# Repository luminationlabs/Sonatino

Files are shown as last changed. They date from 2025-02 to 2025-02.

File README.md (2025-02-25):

# Sonatino PCB Design Files

Sonatino is a powerful ESP32-S3-based audio development board that combines high-quality audio processing capabilities with wireless connectivity and extensive I/O options.

## Features

- ESP32-S3-WROOM-1U MCU with 16MB flash and 8MB PSRAM
- High-quality 24-bit/192kHz DAC (WM8524, stereo) and ADC (WM8782, mono)
- 3.2W speaker amplifier (MAX98357A)
- TRRS audio jack supporting input and output
- Stereo headphone amplifier and microphone preamp
- microSD card slot
- WiFi and Bluetooth 5.0 LE connectivity
- USB-C for programming and power
- Battery support with charging circuit
- Configurable audio I/O levels
- Compact form factor

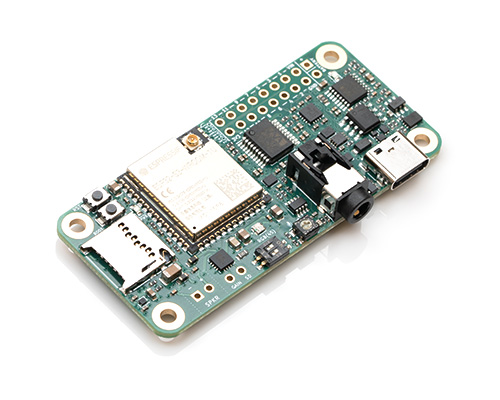
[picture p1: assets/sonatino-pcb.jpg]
Sonatino PCB


## Component Availability

The ADC that Sonatino uses (Cirrus Logic WM8782) has been discontinued by its manufacturer. Some suppliers may still have limited stock, but ultimately it needs to be replaced with a similar ADC (possibly a Texas Instruments PCM186x chip or an audio CODEC to replace the ADC and DAC). In either case, the PCB schematic and layout will need to be modified as there is no drop-in replacement.

## Board Variants

### [Sonatino](https://github.com/luminationlabs/Sonatino) (`main` branch)

- Standard board documented at [sonatino.com](https://sonatino.com)
- Based on ESP32-S3-WROOM-1U
- Uses Bluetooth 5.0 LE **without** support for Bluetooth audio

### [Sonatino - Bluetooth Audio Edition](https://github.com/luminationlabs/Sonatino/tree/btaudio) (`btaudio` branch)

- Unreleased board
- Based on ESP32-WROOM-32UE
- Uses Bluetooth v4.2 BR/EDR and BLE **with** support for Bluetooth audio (A2DP)
- Has fewer exposed GPIO pins (10 vs 13)
- Requires configuration using shift register on GPIO 17, 18, and 19

## License and Trademark Notice

OSHW Logo
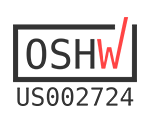
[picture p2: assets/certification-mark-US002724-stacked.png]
Certification Mark


Certified open source hardware ([oshwa.org/cert](https://oshwa.org/cert)) - [OSHW] US002724

The design files for this PCB are open-source hardware under [CERN OHL-P v2.0](https://ohwr.org/cern_ohl_p_v2.txt).

The name "Sonatino" and the associated logo are trademarks of Lumination Labs, Inc. Other manufacturers may use the hardware design but may not use the "Sonatino" branding without permission.

The documentation for Sonatino is copyrighted by Lumination Labs, Inc. and provided for informational purposes only. Redistribution or modification of the documentation requires written permission.

## Documentation

For detailed documentation, examples, and a getting started guide, visit:

- [Documentation](https://sonatino.com/docs/)
- [Example Projects](https://github.com/luminationlabs/Sonatino-Examples)

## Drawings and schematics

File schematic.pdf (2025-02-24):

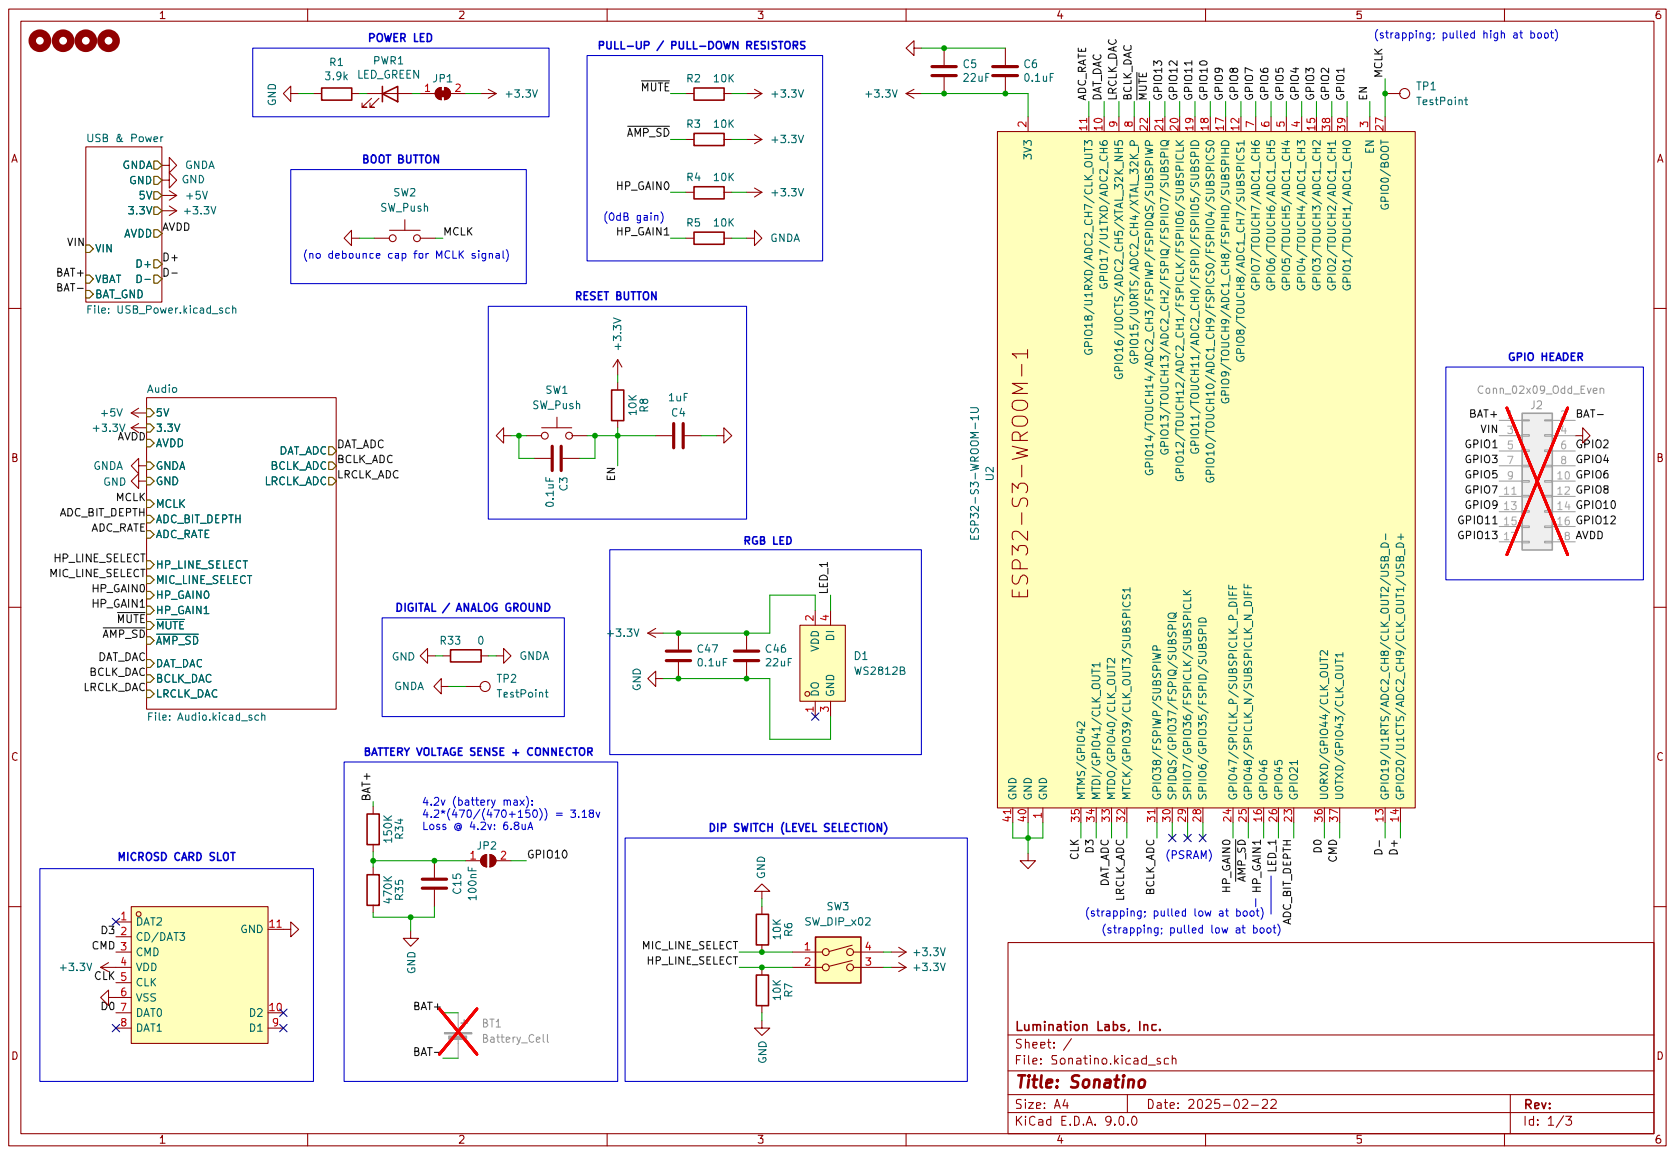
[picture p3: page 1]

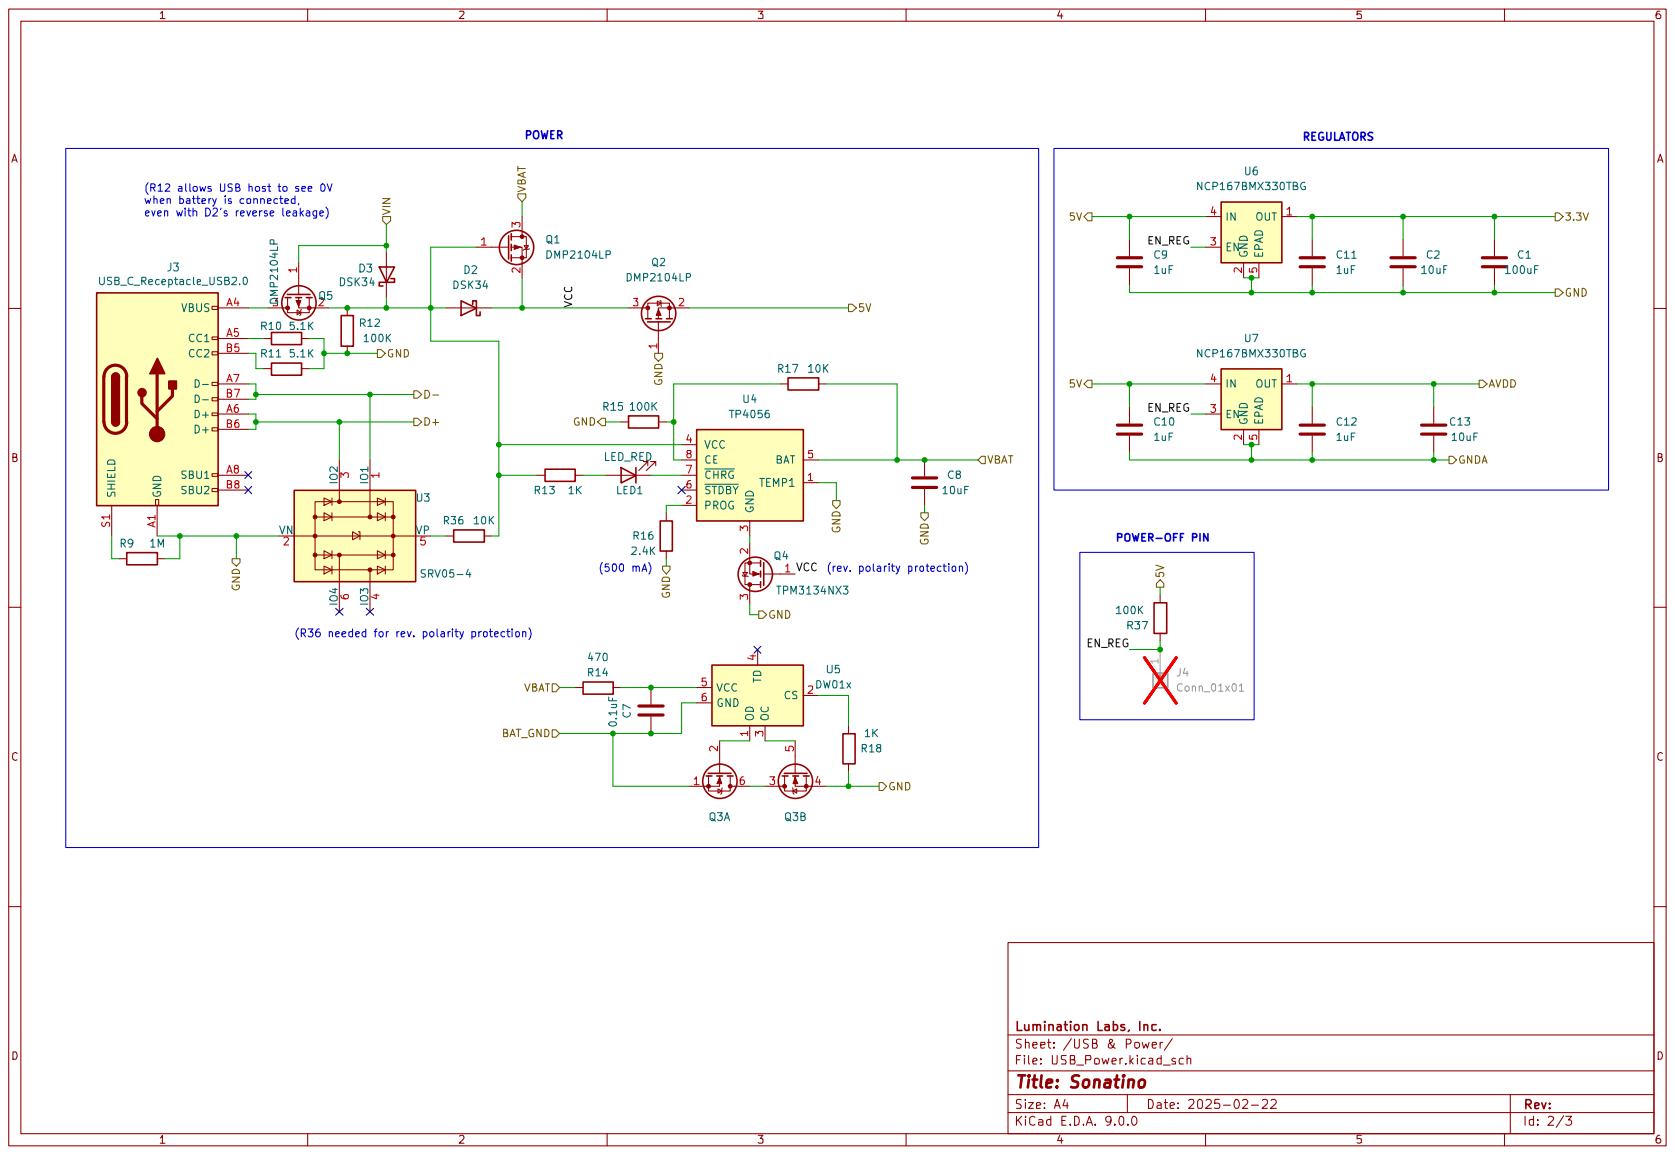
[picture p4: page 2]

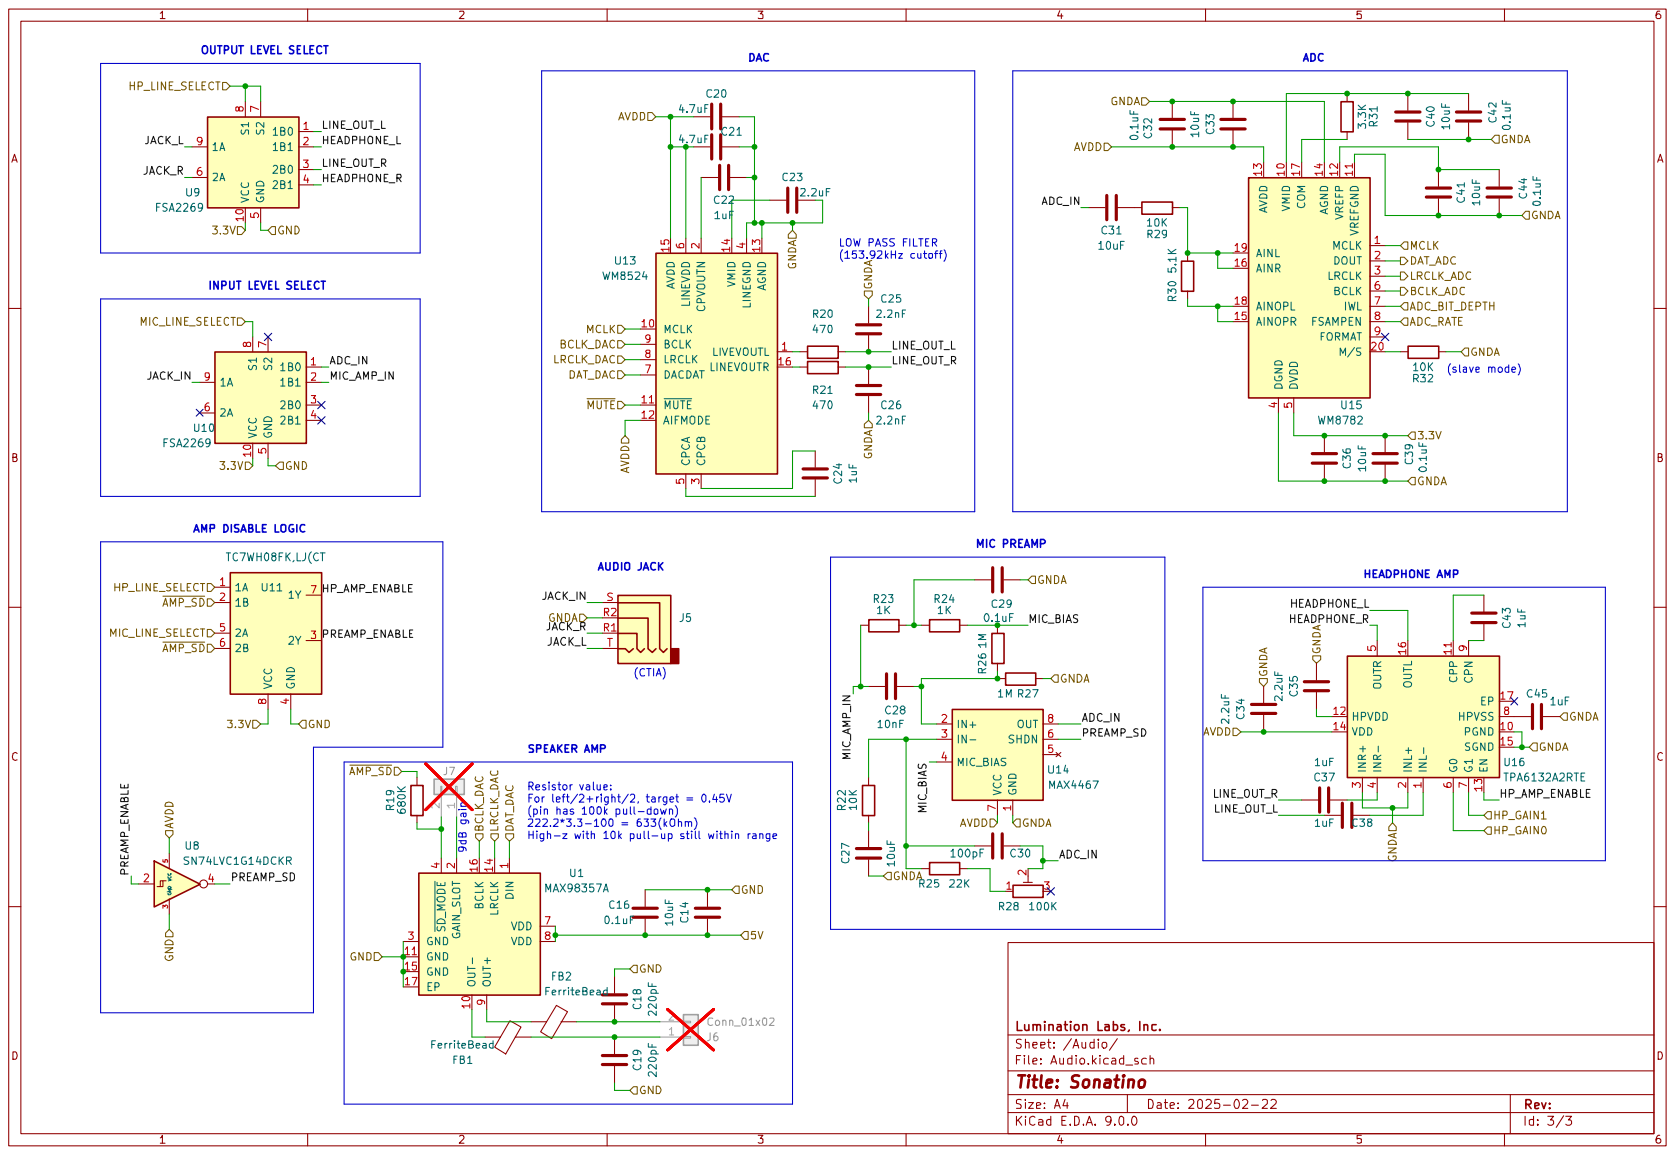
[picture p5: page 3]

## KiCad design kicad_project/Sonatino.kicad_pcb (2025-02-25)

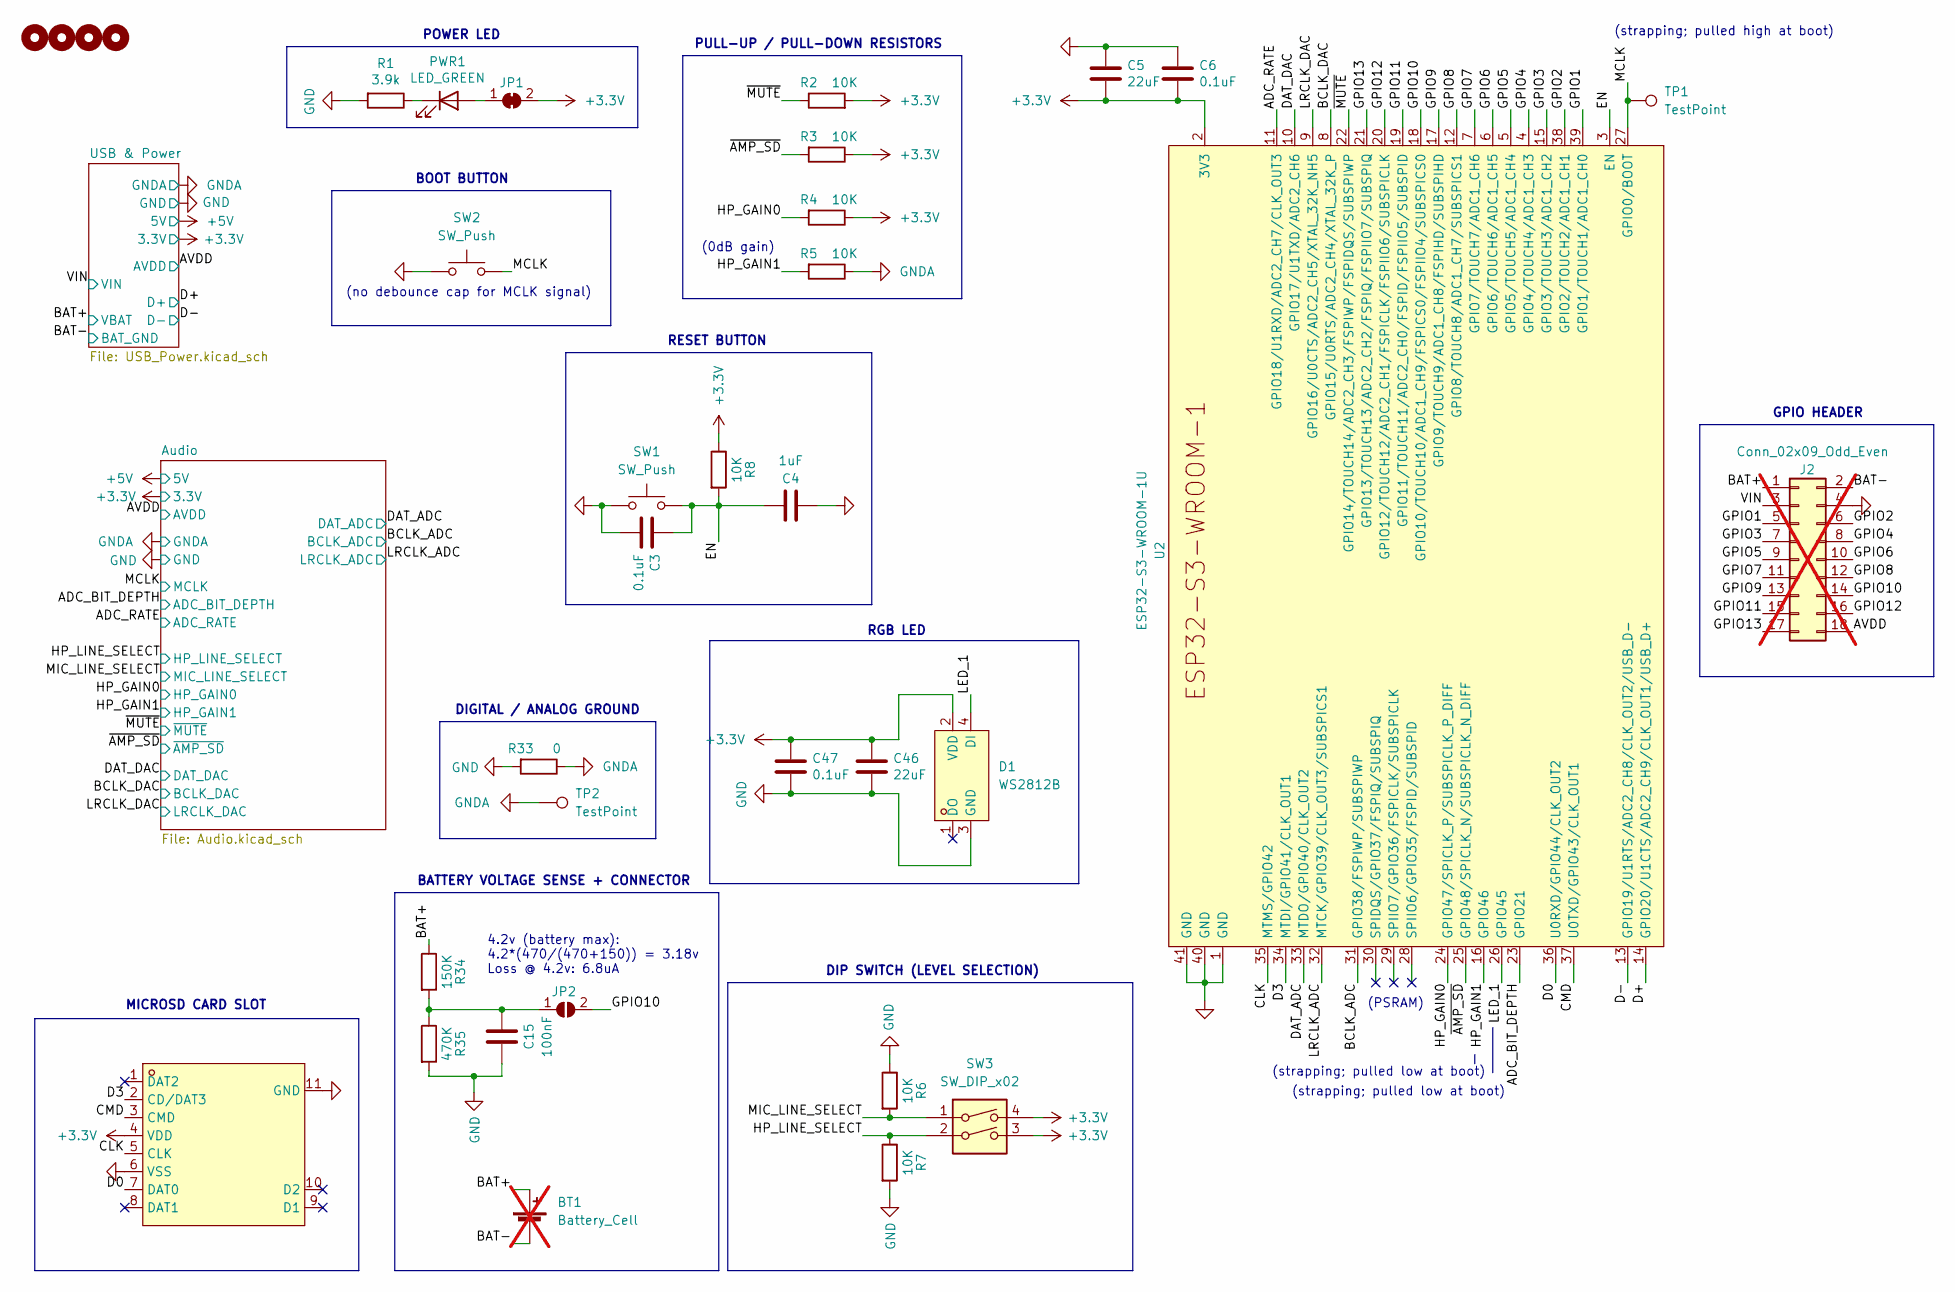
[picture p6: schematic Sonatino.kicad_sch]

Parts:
BT1: Battery_Cell; JST_PH_S2B-PH-SM4-TB_1x02-1MP_P2.00mm_Horizontal; LCSC 0; not fitted
C3, C6, C47: 0.1uF; C_0402_1005Metric; LCSC C307331
C4: 1uF; C_0402_1005Metric; LCSC C52923
C5, C46: 22uF; C_0805_2012Metric; LCSC C45783
C15: 100nF; C_0402_1005Metric; LCSC C1525
Card2: TF-008; TF-SMD_TF-008; LCSC C428465
D1: WS2812B; LED-SMD_4P-L1.6-W1.5_XL-1615RGBC-WS2812B; LCSC C5349954
H1, H3, H5, H7: MountingHole; MountingHole_2.7mm_Pad; LCSC 0
J2: Conn_02x09_Odd_Even; PinHeader_2x09_P2.54mm_Vertical; LCSC 0; not fitted
JP1: SolderJumper_2_Bridged; SolderJumper-2_P1.3mm_Bridged_Pad1.0x1.5mm; LCSC 0
JP2: SolderJumper_2_Open; SolderJumper-2_P1.3mm_Open_TrianglePad1.0x1.5mm; LCSC 0
PWR1: LED_GREEN; LED_0603_1608Metric; LCSC C12624
R1: 3.9k; R_0402_1005Metric; LCSC C51721
R2, R3, R4, R5, R6, R7, R8: 10K; R_0402_1005Metric; LCSC C25744
R33: 0; R_0603_1608Metric; LCSC C21189
R34: 150K; R_0402_1005Metric; LCSC C102813
R35: 470K; R_0402_1005Metric; LCSC C25790
SW1, SW2: SW_Push; SW_Push_1P1T_NO_3.95_2.9; LCSC C354946
SW3: SW_DIP_x02; SW_DIP_SPSTx02_Slide_Omron_A6H-2101_W6.15mm_P1.27mm; LCSC C224995
TP1, TP2: TestPoint; TestPoint_Pad_D1.5mm; LCSC 0
U2: ESP32-S3-WROOM-1U; LCSC C3013946

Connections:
+3.3V: C5.2, C6.2, C46.1, C47.1, Card2.4 (VDD), D1.2 (VDD), JP1.2 (B), R2.2, R3.1, R4.1, R8.1, SW3.3, SW3.4, U2.2 (3V3); also elsewhere on the board
/ADC_BIT_DEPTH: U2.23 (GPIO21); also elsewhere on the board
/ADC_RATE: U2.11 (GPIO18/U1RXD/ADC2_CH7/CLK_OUT3); also elsewhere on the board
/AVDD: J2.18; also elsewhere on the board
/BAT+: BT1.1 (+), J2.1, R34.1; also elsewhere on the board
/BAT-: BT1.2 (-), J2.2; also elsewhere on the board
/BCLK_ADC: U2.31 (GPIO38/FSPIWP/SUBSPIWP); also elsewhere on the board
/BCLK_DAC: U2.8 (GPIO15/U0RTS/ADC2_CH4/XTAL_32K_P); also elsewhere on the board
/CLK: Card2.5 (CLK), U2.35 (MTMS/GPIO42)
/CMD: Card2.3 (CMD), U2.37 (U0TXD/GPIO43/CLK_OUT1)
/D0: Card2.7 (DAT0), U2.36 (U0RXD/GPIO44/CLK_OUT2)
/D3: Card2.2 (CD/DAT3), U2.34 (MTDI/GPIO41/CLK_OUT1)
/D+: U2.14 (GPIO20/U1CTS/ADC2_CH9/CLK_OUT1/USB_D+); also elsewhere on the board
/D-: U2.13 (GPIO19/U1RTS/ADC2_CH8/CLK_OUT2/USB_D-); also elsewhere on the board
/DAT_ADC: U2.33 (MTDO/GPIO40/CLK_OUT2); also elsewhere on the board
/DAT_DAC: U2.10 (GPIO17/U1TXD/ADC2_CH6); also elsewhere on the board
/EN: C3.1, C4.2, R8.2, SW1.2, U2.3 (EN)
/GPIO1: J2.5, U2.39 (GPIO1/TOUCH1/ADC1_CH0)
/GPIO2: J2.6, U2.38 (GPIO2/TOUCH2/ADC1_CH1)
/GPIO3: J2.7, U2.15 (GPIO3/TOUCH3/ADC1_CH2)
/GPIO4: J2.8, U2.4 (GPIO4/TOUCH4/ADC1_CH3)
/GPIO5: J2.9, U2.5 (GPIO5/TOUCH5/ADC1_CH4)
/GPIO6: J2.10, U2.6 (GPIO6/TOUCH6/ADC1_CH5)
/GPIO7: J2.11, U2.7 (GPIO7/TOUCH7/ADC1_CH6)
/GPIO8: J2.12, U2.12 (GPIO8/TOUCH8/ADC1_CH7/SUBSPICS1)
/GPIO9: J2.13, U2.17 (GPIO9/TOUCH9/ADC1_CH8/FSPIHD/SUBSPIHD)
/GPIO10: J2.14, JP2.2 (B), U2.18 (GPIO10/TOUCH10/ADC1_CH9/FSPICS0/FSPIIO4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)
/GPIO11: J2.15, U2.19 (GPIO11/TOUCH11/ADC2_CH0/FSPID/FSPIIO5/S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)
/GPIO12: J2.16, U2.20 (GPIO12/TOUCH12/ADC2_CH1/FSPICLK/FSPIIO6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)
/GPIO13: J2.17, U2.21 (GPIO13/TOUCH13/ADC2_CH2/FSPIQ/FSPIIO7/S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)
/HP_GAIN0: R4.2, U2.24 (GPIO47/SPICLK_P/SUBSPICLK_P_DIFF); also elsewhere on the board
/HP_GAIN1: R5.2, U2.16 (GPIO46); also elsewhere on the board
/HP_LINE_SELECT: R7.1, SW3.2; also elsewhere on the board
/LED_1: D1.4 (DI), U2.26 (GPIO45)
/LRCLK_ADC: U2.32 (MTCK/GPIO39/CLK_OUT3/SUBSPICS1); also elsewhere on the board
/LRCLK_DAC: U2.9 (GPIO16/U0CTS/ADC2_CH5/XTAL_32K_NH5); also elsewhere on the board
/MCLK: SW2.2, TP1.1, U2.27 (GPIO0/BOOT); also elsewhere on the board
/MIC_LINE_SELECT: R6.2, SW3.1; also elsewhere on the board
/VIN: J2.3; also elsewhere on the board
/~AMP_SD: R3.2, U2.25 (GPIO48/SPICLK_N/SUBSPICLK_N_DIFF); also elsewhere on the board
/~MUTE: R2.1, U2.22 (GPIO14/TOUCH14/ADC2_CH3/FSPIWP/FSPIDQS/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); also elsewhere on the board
GND: C3.2, C4.1, C5.1, C6.1, C15.1, C46.2, C47.2, Card2.6 (VSS), Card2.11 (GND), D1.3 (GND), J2.4, R1.2, R6.1, R7.2, R33.2, R35.2, SW1.1, SW2.1, U2.1 (GND), U2.40 (GND), U2.41 (GND); also elsewhere on the board
GNDA: R5.1, R33.1, TP2.1; also elsewhere on the board
unnamed: JP1.1 (A), PWR1.2 (A)
unnamed: C15.2, JP2.1 (A), R34.2, R35.1
unnamed: PWR1.1 (K), R1.1

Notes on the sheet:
(PSRAM)
(no debounce cap for MCLK signal)
DIP SWITCH (LEVEL SELECTION)
(strapping; pulled low at boot)
(0dB gain)
BOOT BUTTON
GPIO HEADER
(strapping; pulled high at boot)
RESET BUTTON
4.2v (battery max): 4.2*(470/(470+150)) = 3.18v Loss @ 4.2v: 6.8uA
DIGITAL / ANALOG GROUND
BATTERY VOLTAGE SENSE + CONNECTOR
RGB LED
MICROSD CARD SLOT
PULL-UP / PULL-DOWN RESISTORS
POWER LED

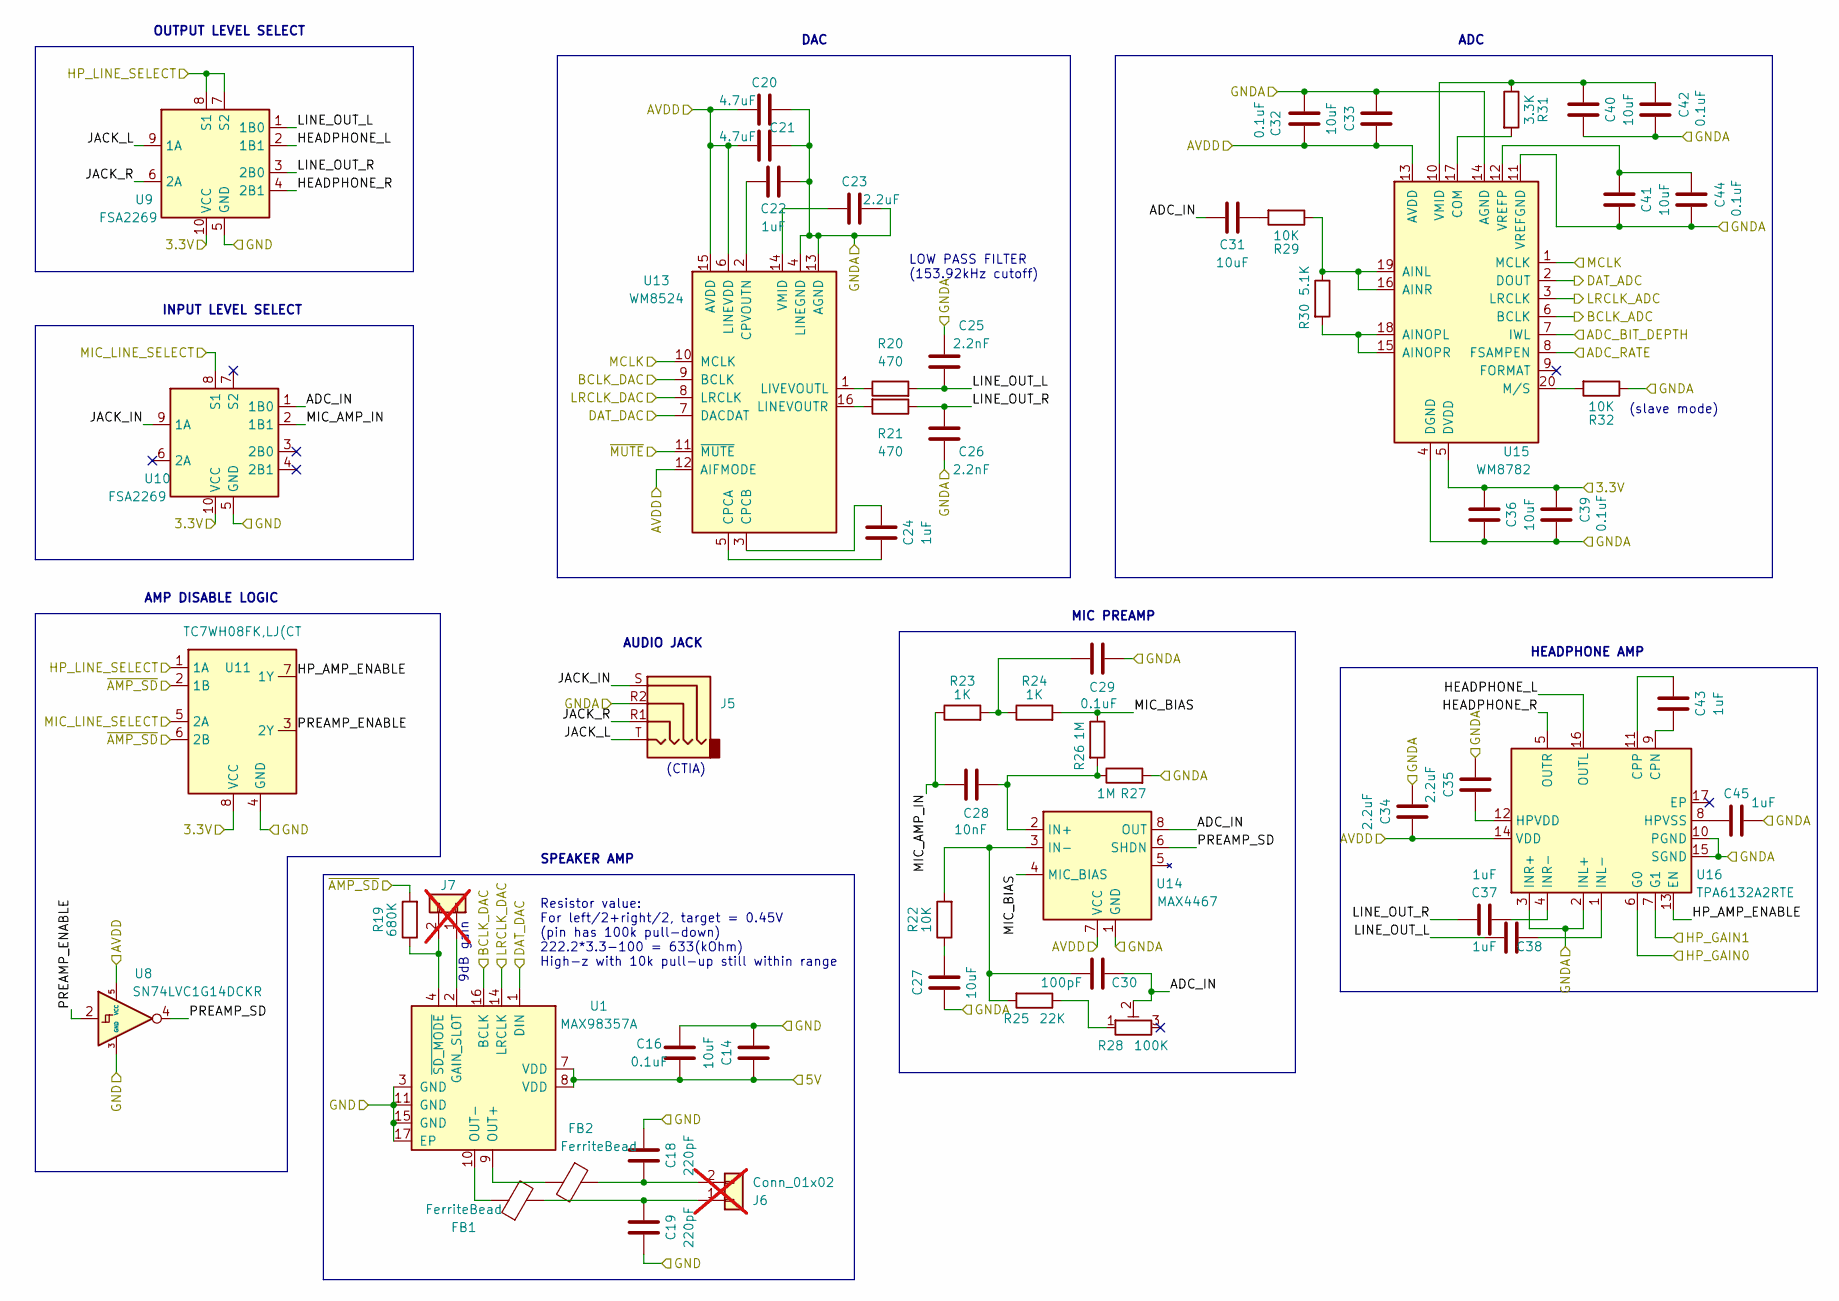
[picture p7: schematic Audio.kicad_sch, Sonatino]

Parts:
C14: 10uF; C_0805_2012Metric; LCSC C15850
C16: 0.1uF; C_0805_2012Metric; LCSC C49678
C18, C19: 220pF; C_0402_1005Metric; LCSC C1530
C20, C21: 4.7uF; C_0402_1005Metric; LCSC C23733
C22, C37, C38, C43, C45: 1uF; C_0402_1005Metric; LCSC C52923
C23, C34, C35: 2.2uF; C_0402_1005Metric; LCSC C12530
C24: 1uF; C_0603_1608Metric; LCSC C15849
C25, C26: 2.2nF; C_0402_1005Metric; LCSC C1531
C27, C31, C33, C36, C40, C41: 10uF; C_0402_1005Metric; LCSC C15525
C28: 10nF; C_0402_1005Metric; LCSC C15195
C29, C32, C39, C42, C44: 0.1uF; C_0402_1005Metric; LCSC C307331
C30: 100pF; C_0402_1005Metric; LCSC C1546
FB1, FB2: FerriteBead; L_0603_1608Metric; LCSC C1002
J5: AudioJack4; PJ-321B; LCSC C692436
J6: Conn_01x02; PinHeader_1x02_P2.54mm_Vertical; LCSC 0; not fitted
J7: Conn_01x02; PinHeader_1x02_P2.54mm_Vertical; not fitted
R19: 680K; R_0603_1608Metric; LCSC C25822
R20, R21: 470; R_0402_1005Metric; LCSC C25117
R22, R29, R32: 10K; R_0402_1005Metric; LCSC C25744
R23, R24: 1K; R_0402_1005Metric; LCSC C11702
R25: 22K; R_0402_1005Metric; LCSC C25768
R26, R27: 1M; R_0402_1005Metric; LCSC C26083
R28: 100K; G32AT-B103; LCSC C128123
R30: 5.1K; R_0402_1005Metric; LCSC C25905
R31: 3.3K; R_0402_1005Metric; LCSC C25890
U1: MAX98357A; TQFN-16-1EP_3x3mm_P0.5mm_EP1.23x1.23mm; JLCPCB Rotation Offset 270
U8: SN74LVC1G14DCKR; SOT-353_SC-70-5; LCSC C2976657
U9, U10: FSA2269; Fairchild_MicroPak-10_2.10x1.6mm_P0.5mm; LCSC C895405
U11: TC7WH08FK,LJ(CT; VSSOP-8_2.3x2mm_P0.5mm; LCSC C2880449
U13: WM8524; TSSOP-16_4.4x5mm_P0.65mm; LCSC C146242
U14: MAX4467; SOT-23-8; LCSC C490742
U15: WM8782; SSOP-20_5.3x7.2mm_P0.65mm; LCSC C323842
U16: TPA6132A2RTE; WQFN-16-1EP_3x3mm_P0.5mm_EP1.6x1.6mm_ThermalVias; LCSC C69901

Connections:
+3.3V: C36.2, C39.1, U9.10 (VCC), U10.10 (VCC), U11.8 (VCC), U15.5 (DVDD); also elsewhere on the board
+5V: C14.2, C16.1, U1.7 (VDD), U1.8 (VDD); also elsewhere on the board
/ADC_BIT_DEPTH: U15.7 (IWL); also elsewhere on the board
/ADC_RATE: U15.8 (FSAMPEN); also elsewhere on the board
/AVDD: C20.1, C21.1, C32.1, C33.2, C34.2, U8.5 (VCC), U13.6 (LINEVDD), U13.12 (AIFMODE), U13.15 (AVDD), U14.7 (VCC), U15.13 (AVDD), U16.14 (VDD); also elsewhere on the board
/Audio/ADC_IN: C30.2, C31.1, R28.2, U10.1 (1B0), U14.8 (OUT)
/Audio/HEADPHONE_L: U9.2 (1B1), U16.16 (OUTL)
/Audio/HEADPHONE_R: U9.4 (2B1), U16.5 (OUTR)
/Audio/HP_AMP_ENABLE: U11.7 (1Y), U16.13 (EN)
/Audio/JACK_IN: J5.S, U10.9 (1A)
/Audio/JACK_L: J5.T, U9.9 (1A)
/Audio/JACK_R: J5.R1, U9.6 (2A)
/Audio/LINE_OUT_L: C25.1, C38.1, R20.2, U9.1 (1B0)
/Audio/LINE_OUT_R: C26.2, C37.2, R21.1, U9.3 (2B0)
/Audio/MIC_AMP_IN: C28.2, R23.1, U10.2 (1B1)
/Audio/MIC_BIAS: R24.2, R26.1, U14.4 (MIC_BIAS)
/Audio/PREAMP_ENABLE: U8.2, U11.3 (2Y)
/Audio/PREAMP_SD: U8.4, U14.6 (SHDN)
/BCLK_ADC: U15.6 (BCLK); also elsewhere on the board
/BCLK_DAC: U1.16 (BCLK), U13.9 (BCLK); also elsewhere on the board
/DAT_ADC: U15.2 (DOUT); also elsewhere on the board
/DAT_DAC: U1.1 (DIN), U13.7 (DACDAT); also elsewhere on the board
/HP_GAIN0: U16.6 (G0); also elsewhere on the board
/HP_GAIN1: U16.7 (G1); also elsewhere on the board
/HP_LINE_SELECT: U9.7 (S2), U9.8 (S1), U11.1 (1A); also elsewhere on the board
/LRCLK_ADC: U15.3 (LRCLK); also elsewhere on the board
/LRCLK_DAC: U1.14 (LRCLK), U13.8 (LRCLK); also elsewhere on the board
/MCLK: U13.10 (MCLK), U15.1 (MCLK); also elsewhere on the board
/MIC_LINE_SELECT: U10.8 (S1), U11.5 (2A); also elsewhere on the board
/~AMP_SD: R19.2, U11.2 (1B), U11.6 (2B); also elsewhere on the board
/~MUTE: U13.11 (~MUTE); also elsewhere on the board
GND: C14.1, C16.2, C18.2, C19.1, U1.3 (GND), U1.11 (GND), U1.15 (GND), U1.17 (EP), U8.3 (GND), U9.5 (GND), U10.5 (GND), U11.4 (GND); also elsewhere on the board
GNDA: C20.2, C21.2, C22.2, C23.1, C25.2, C26.1, C27.2, C29.1, C32.2, C33.1, C34.1, C35.1, C36.1, C39.2, C40.1, C41.1, C42.2, C44.2, C45.1, J5.R2, R27.2, R32.1, U13.4 (LINEGND), U13.13 (AGND), U14.1 (GND), U15.4 (DGND), U15.11 (VREFGND), U15.14 (AGND), U16.2 (INL+), U16.3 (INR+), U16.10 (PGND), U16.15 (SGND); also elsewhere on the board
unnamed: C27.1, R22.1
unnamed: C29.2, R23.2, R24.1
unnamed: C31.2, R29.2
unnamed: C19.2, FB1.2, J6.1
unnamed: C18.1, FB2.1, J6.2
unnamed: J7.1, U1.2 (GAIN_SLOT)
unnamed: J7.2, R19.1, U1.4 (~SD_MODE)
unnamed: R25.1, R28.1
unnamed: FB2.2, U1.9 (OUT+)
unnamed: FB1.1, U1.10 (OUT-)
unnamed: C24.1, U13.5 (CPCA)
unnamed: C24.2, U13.3 (CPCB)
unnamed: C22.1, U13.2 (CPVOUTN)
unnamed: R21.2, U13.16 (LINEVOUTR)
unnamed: R20.1, U13.1 (LIVEVOUTL)
unnamed: C23.2, U13.14 (VMID)
unnamed: C28.1, R26.2, R27.1, U14.2 (IN+)
unnamed: C30.1, R22.2, R25.2, U14.3 (IN-)
unnamed: R29.1, R30.1, U15.16 (AINR), U15.19 (AINL)
unnamed: R30.2, U15.15 (AINOPR), U15.18 (AINOPL)
unnamed: R31.2, U15.17 (COM)
unnamed: R32.2, U15.20 (M/S)
unnamed: C40.2, C42.1, R31.1, U15.10 (VMID)
unnamed: C41.2, C44.1, U15.12 (VREFP)
unnamed: C43.1, U16.9 (CPN)
unnamed: C43.2, U16.11 (CPP)
unnamed: C35.2, U16.12 (HPVDD)
unnamed: C45.2, U16.8 (HPVSS)
unnamed: C38.2, U16.1 (INL-)
unnamed: C37.1, U16.4 (INR-)

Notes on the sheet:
9dB gain
ADC
MIC PREAMP
LOW PASS FILTER (153.92kHz cutoff)
INPUT LEVEL SELECT
(slave mode)
SPEAKER AMP
AMP DISABLE LOGIC
OUTPUT LEVEL SELECT
AUDIO JACK
Resistor value: For left/2+right/2, target = 0.45V (pin has 100k pull-down) 222.2*3.3-100 = 633(kOhm) High-z with 10k pull-up still within range
DAC
HEADPHONE AMP
(CTIA)

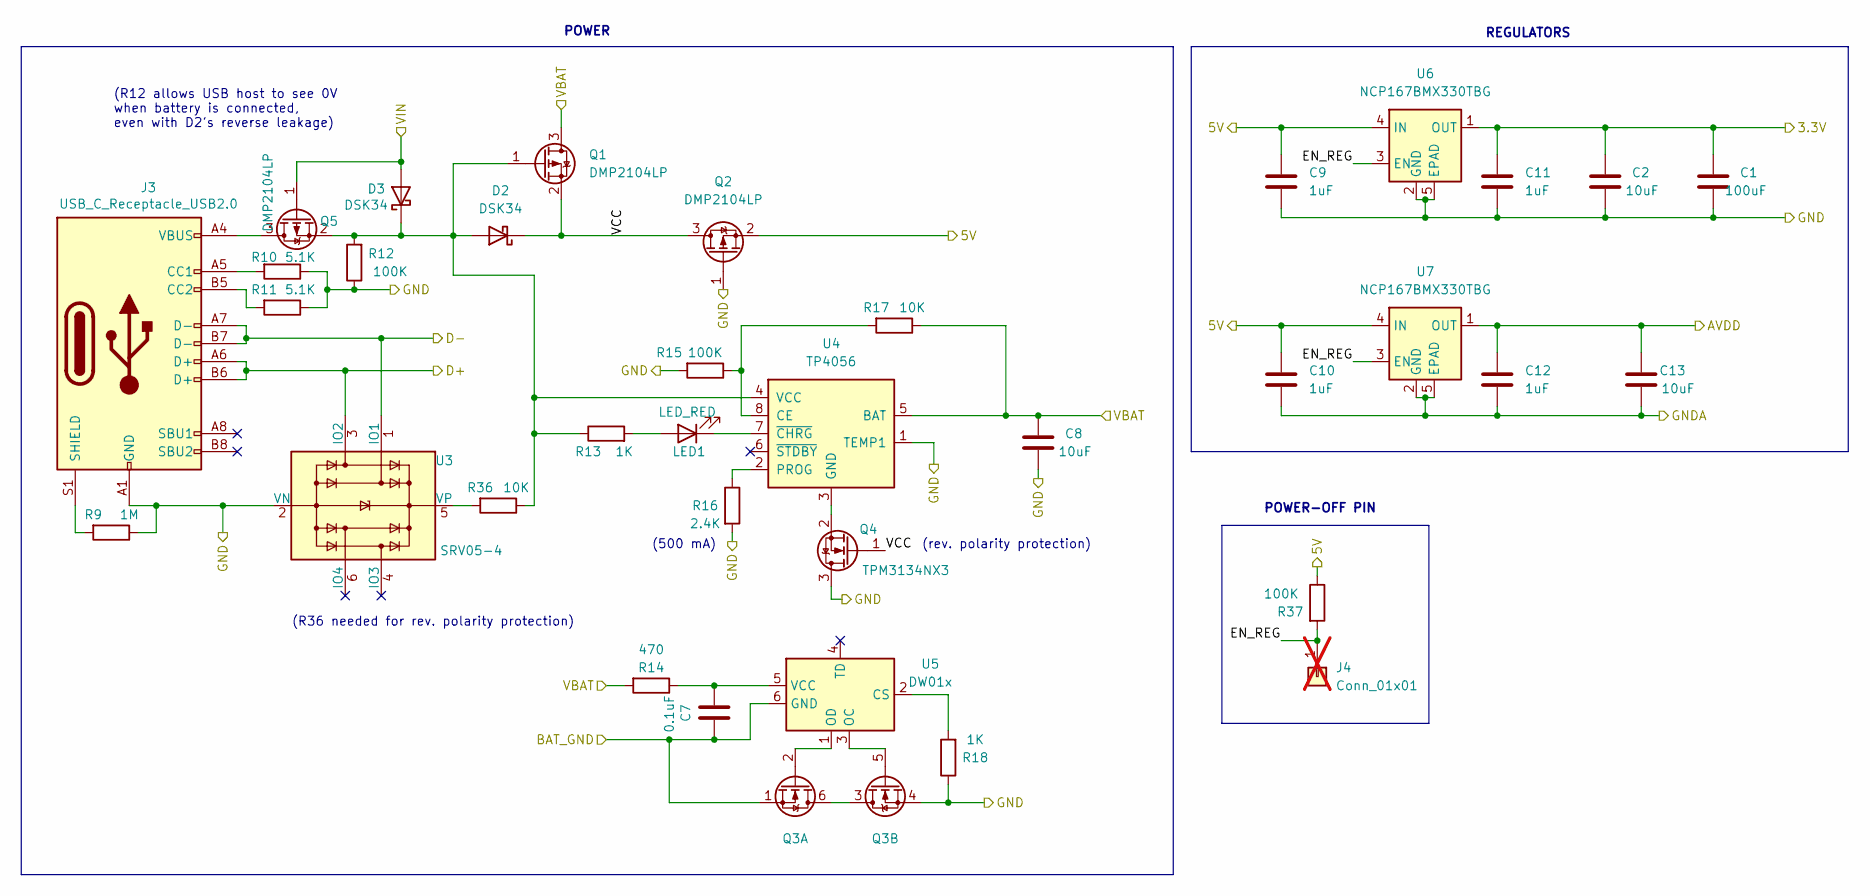
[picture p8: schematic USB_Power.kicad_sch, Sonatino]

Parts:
C1: 100uF; C_1206_3216Metric; LCSC C15008
C2, C13: 10uF; C_0603_1608Metric; LCSC C19702
C7: 0.1uF; C_0402_1005Metric; LCSC C307331
C8: 10uF; C_0402_1005Metric; LCSC C15525
C9, C10, C11, C12: 1uF; C_0402_1005Metric; LCSC C52923
D2, D3: DSK34; SOD-123FL; LCSC C41029
J3: USB_C_Receptacle_USB2.0; USB_C_Receptacle_HRO_TYPE-C-31-M-12; LCSC C165948
J4: Conn_01x01; PinHeader_1x01_P2.54mm_Vertical; LCSC 0; not fitted
LED1: LED_RED; LED_0603_1608Metric; LCSC C2286
Q1, Q2, Q5: DMP2104LP; Diodes_DFN1411-3; LCSC C260933
Q3: HSCC8233; DFN-6-1EP_3x2mm_P0.5mm_EP1.65x1.35mm_Dual_MOSFETs; LCSC C700968
Q4: TPM3134NX3; SOT-723; LCSC C558450
R9: 1M; R_0402_1005Metric; LCSC C26083
R10, R11: 5.1K; R_0402_1005Metric; LCSC C25905
R12, R15, R37: 100K; R_0402_1005Metric; LCSC C25741
R13, R18: 1K; R_0402_1005Metric; LCSC C11702
R14: 470; R_0402_1005Metric; LCSC C25117
R16: 2.4K; R_0402_1005Metric; LCSC C25882
R17, R36: 10K; R_0402_1005Metric; LCSC C25744
U3: SRV05-4; SOT-23-6; LCSC C85364
U4: TP4056; TI_SO-PowerPAD-8; LCSC C16581
U5: DW01x; SOT-23-6; LCSC C351410
U6, U7: NCP167BMX330TBG; OnSemi_XDFN4-1EP_1.0x1.0mm_EP0.52x0.52mm-FIXED; LCSC C892227

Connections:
+3.3V: C1.2, C2.2, C11.1, U6.1 (OUT); also elsewhere on the board
+5V: C9.1, C10.1, Q2.2 (S), R37.1, U6.4 (IN), U7.4 (IN); also elsewhere on the board
/AVDD: C12.1, C13.2, U7.1 (OUT); also elsewhere on the board
/BAT+: C8.2, Q1.3 (D), R14.2, R17.1, U4.5 (BAT); also elsewhere on the board
/BAT-: C7.1, Q3.1 (S), U5.6 (GND); also elsewhere on the board
/D+: J3.A6 (D+), J3.B6 (D+), U3.3 (IO2); also elsewhere on the board
/D-: J3.A7 (D-), J3.B7 (D-), U3.1 (IO1); also elsewhere on the board
/USB & Power/EN_REG: J4.1, R37.2, U6.3 (EN), U7.3 (EN)
/USB & Power/VCC: D2.1 (K), Q1.2 (S), Q2.3 (D), Q4.1 (G)
/VIN: D3.2 (A), Q5.1 (G); also elsewhere on the board
GND: C1.1, C2.1, C8.1, C9.2, C11.2, J3.A1 (GND), J3.A12 (GND), J3.B1 (GND), J3.B12 (GND), Q2.1 (G), Q3.4 (S), Q4.3 (D), R9.1, R10.1, R11.1, R12.1, R15.2, R16.2, R18.1, U3.2 (VN), U4.1 (TEMP1), U6.2 (GND), U6.5 (EPAD); also elsewhere on the board
GNDA: C10.2, C12.2, C13.1, U7.2 (GND), U7.5 (EPAD); also elsewhere on the board
unnamed: D2.2 (A), D3.1 (K), Q1.1 (G), Q5.2 (S), R12.2, R13.1, R36.1, U4.4 (VCC)
unnamed: J3.A5 (CC1), R10.2
unnamed: J3.B5 (CC2), R11.2
unnamed: J3.S1 (SHIELD), R9.2
unnamed: LED1.2 (A), R13.2
unnamed: LED1.1 (K), U4.7 (~CHRG)
unnamed: Q3.3 (D), Q3.6 (D)
unnamed: Q3.2 (G), U5.1 (OD)
unnamed: Q3.5 (G), U5.3 (OC)
unnamed: Q4.2 (S), U4.3 (GND)
unnamed: J3.A4 (VBUS), J3.A9 (VBUS), J3.B4 (VBUS), J3.B9 (VBUS), Q5.3 (D)
unnamed: R36.2, U3.5 (VP)
unnamed: R15.1, R17.2, U4.8 (CE)
unnamed: R16.1, U4.2 (PROG)
unnamed: R18.2, U5.2 (CS)
unnamed: C7.2, R14.1, U5.5 (VCC)

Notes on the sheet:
POWER
(R12 allows USB host to see 0V when battery is connected, even with D2's reverse leakage)
(500 mA)
(R36 needed for rev. polarity protection)
(rev. polarity protection)
POWER-OFF PIN
REGULATORS

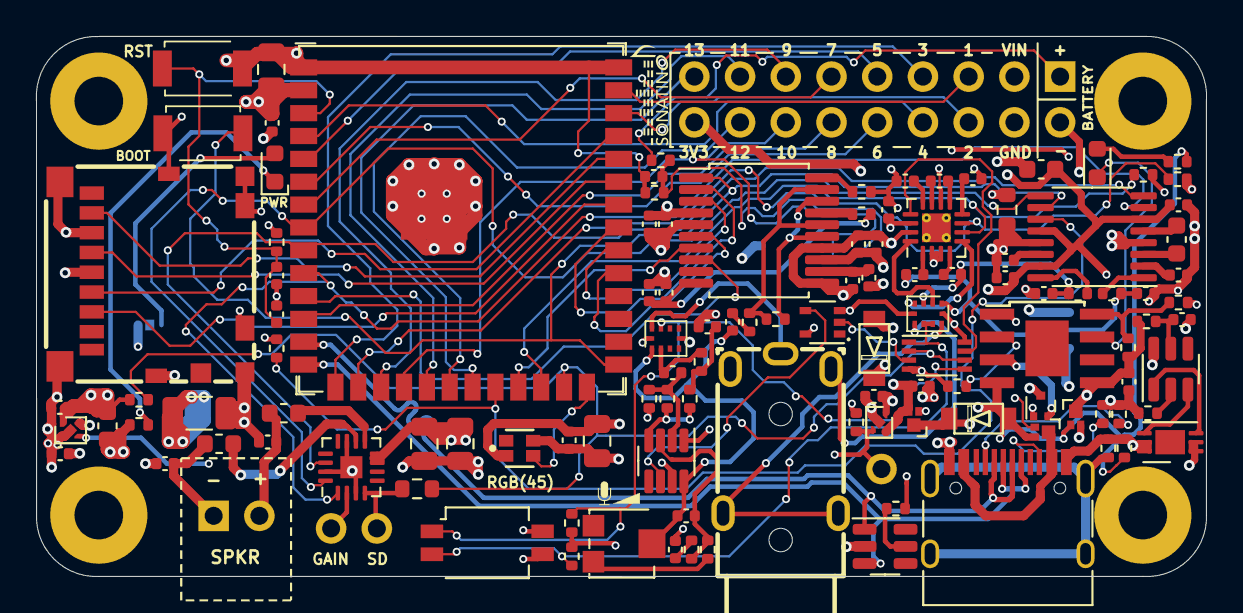
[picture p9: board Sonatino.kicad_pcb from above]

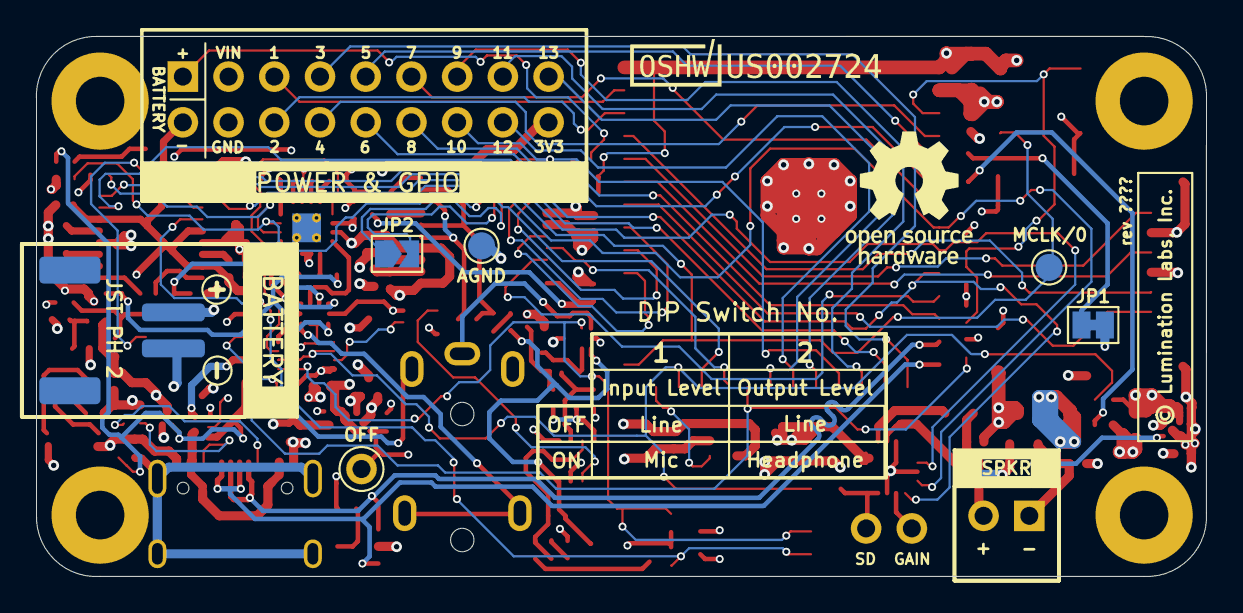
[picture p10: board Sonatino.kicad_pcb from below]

Board: 4 copper layers, 65.0 x 30.0 mm, 129 parts (5 on the bottom side), 108 nets.

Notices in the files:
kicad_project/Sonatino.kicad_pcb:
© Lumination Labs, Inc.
